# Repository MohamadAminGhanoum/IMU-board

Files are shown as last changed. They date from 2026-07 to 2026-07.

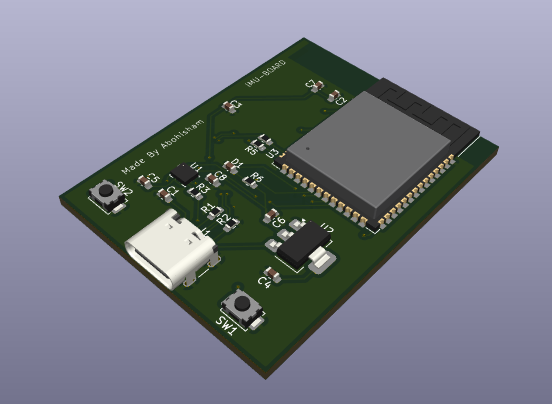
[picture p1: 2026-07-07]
IMU board assets/Screenshot 2026-07-07 at 11.47.12.png

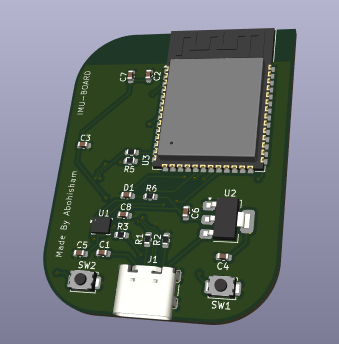
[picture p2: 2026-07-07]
IMU board assets/Screenshot 2026-07-07 at 11.54.32.png

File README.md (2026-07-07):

# IMU-board
Im making a module that has small sensors on the pcbs, which will give me motion data, which i will track and recieve on either my phone or computer using the usb-c. i have planned to use components to measure acceleration, and gestures, etc. i have done some research, and i have decided to use the ST ISM330DHCXTR which can be found from LCSC electronics.
I want for instance to test this when im inside the car, and i want to see what data it will provide me, and whether it is accurate compared to my phone (and possibly whether my phone is accurate compared with it ;).



## Schematics:



## PCB



## BOM

|Id |Name |Footprint |Quantity |Price |Value |Supplier |LINK: |
|---|---|---|---|---|---|---|---|
|1  |SW2 |SW_SPST_TS-1088-xR020 |1 |0 |enable |Self-sourced| |
|2  |SW1 |SW_SPST_TS-1088-xR020 |1 |0 |boot |Self-sourced| |
|3  |R5,R4 |R_0603_1608Metric |2 |0 |33r |Self-sourced| |
|4  |U3 |ESP32-S3-WROOM-1 |1 |5.53  |ESP32-S3-WROOM-1 |LCSC |https://www.lcsc.com/product-detail/C2913202.html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|
|5  |U2 |SOT-223-3_TabPin2 |1 |1 |AMS1117-3.3 |LCSC |https://www.lcsc.com/product-detail/C6186.html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 |
|6  |U1 |LGA-14_3x2.5mm_P0.5mm_LayoutBorder3x4y |1 |6.28  |ISM330DHCX |LCSC |https://www.lcsc.com/product-detail/C2655101.html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 |
|7  |R6 |R_0603_1608Metric |1 |0 |1k |Self-sourced| |
|8  |R3 |R_0603_1608Metric |1 |0 |10k |Self-sourced| |
|9  |R2,R1 |R_0603_1608Metric |2 |0 |5.1k |Self-sourced| |
|10 |J1 |USB_C_Receptacle_GCT_USB4105-xx-A_16P_TopMnt_Horizontal|1 |0 |USB_C_Receptacle_USB2.0_14P|self-sourced| |
|11 |D1 |C_0603_1608Metric |1 |0 |LED |self-sourced| |
|12 |C8,C7,C6,C5,C4,C3|C_0603_1608Metric |6 |0 |100nF |self-sourced| |
|13 |C2 |C_0603_1608Metric |1 |0 |22 uF |self-sourced| |
|14 |C1 |C_0603_1608Metric |1 |0 |10 uF |self-sourced| |
|15 |PCB | | |6 | |JLCPCB | |
| | | | | | | | |
| | | |Total cost with shipping:|36 USD| | | |

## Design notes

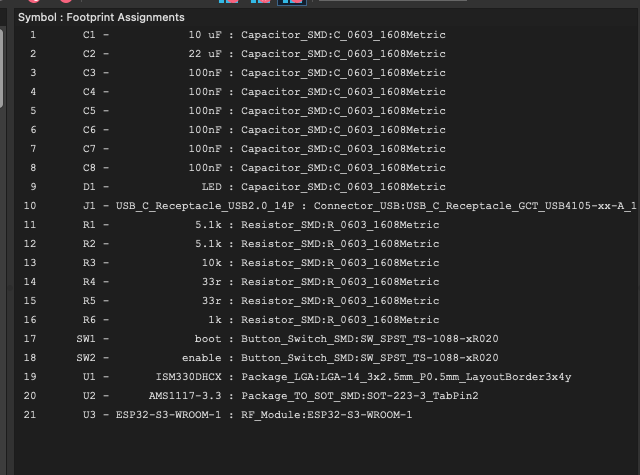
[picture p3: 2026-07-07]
IMU board assets/Screenshot 2026-07-07 at 11.48.55.png

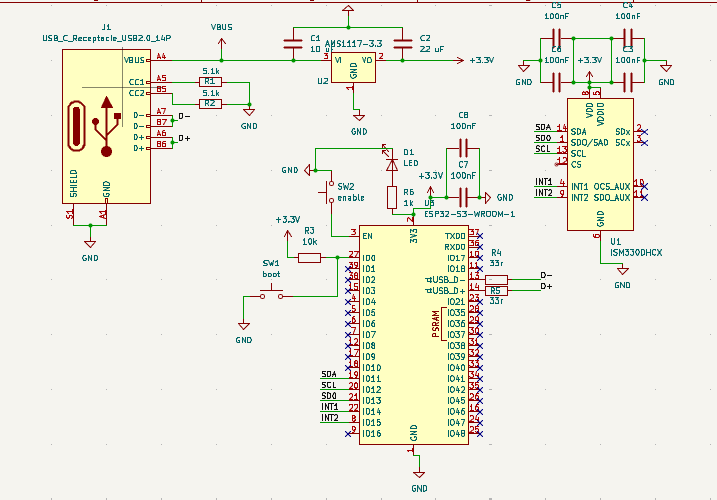
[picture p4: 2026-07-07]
IMU board assets/Screenshot 2026-07-07 at 11.03.52.png

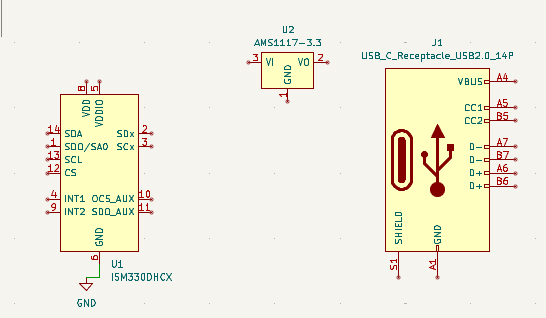
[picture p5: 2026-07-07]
IMU board assets/Screenshot 2026-07-06 at 20.02.14.png

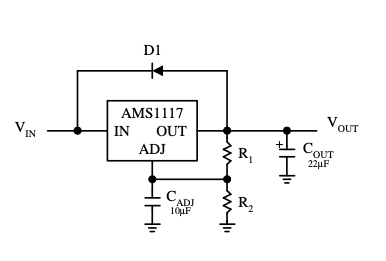
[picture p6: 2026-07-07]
IMU board assets/Screenshot 2026-07-07 at 10.36.37.png

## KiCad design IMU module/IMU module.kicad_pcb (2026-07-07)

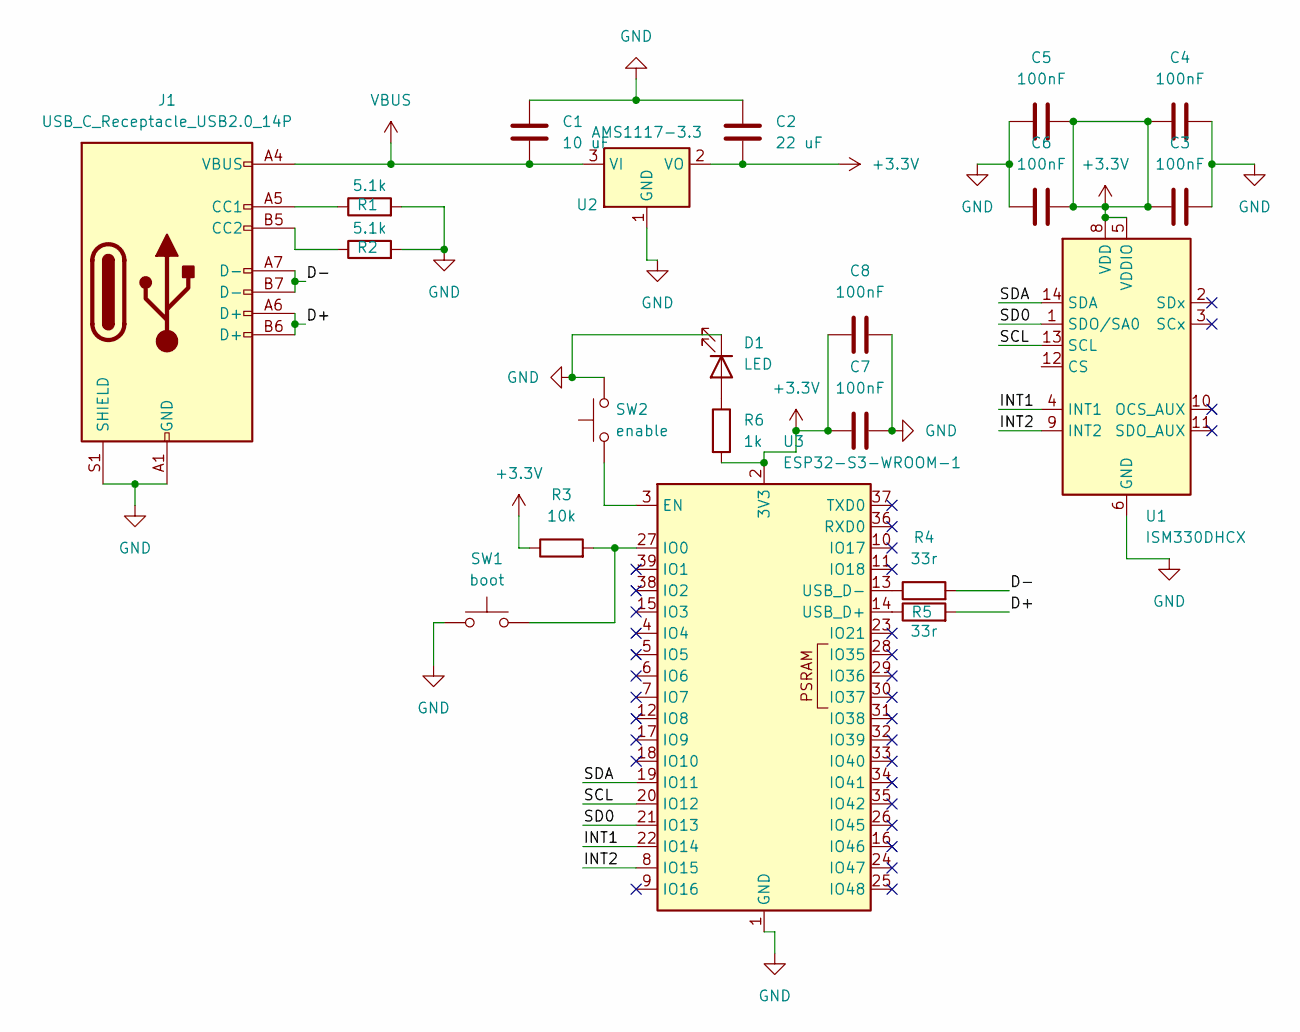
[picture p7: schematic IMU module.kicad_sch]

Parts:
C1: 10 uF; C_0603_1608Metric
C2: 22 uF; C_0603_1608Metric
C3, C4, C5, C6, C7, C8: 100nF; C_0603_1608Metric
D1: LED; C_0603_1608Metric
J1: USB_C_Receptacle_USB2.0_14P; USB_C_Receptacle_GCT_USB4105-xx-A_16P_TopMnt_Horizontal
R1, R2: 5.1k; R_0603_1608Metric
R3: 10k; R_0603_1608Metric
R4, R5: 33r; R_0603_1608Metric
R6: 1k; R_0603_1608Metric
SW1: boot; SW_SPST_TS-1088-xR020
SW2: enable; SW_SPST_TS-1088-xR020
U1: ISM330DHCX; LGA-14_3x2.5mm_P0.5mm_LayoutBorder3x4y
U2: AMS1117-3.3; SOT-223-3_TabPin2
U3: ESP32-S3-WROOM-1

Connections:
+3.3V: C2.2, C3.1, C4.1, C5.2, C6.2, C7.1, C8.1, R3.1, R6.2, U1.5 (VDDIO), U1.8 (VDD), U2.2 (VO), U3.2 (3V3)
/D+: J1.A6 (D+), J1.B6 (D+), R5.2
/D-: J1.A7 (D-), J1.B7 (D-), R4.2
/INT1: U1.4 (INT1), U3.22 (IO14)
/INT2: U1.9 (INT2), U3.8 (IO15)
/SCL: U1.13 (SCL), U3.20 (IO12)
/SD0: U1.1 (SDO/SA0), U3.21 (IO13)
/SDA: U1.14 (SDA), U3.19 (IO11)
GND: C1.1, C2.1, C3.2, C4.2, C5.1, C6.1, C7.2, C8.2, D1.1 (K), J1.A1 (GND), J1.A12 (GND), J1.B1 (GND), J1.B12 (GND), J1.S1 (SHIELD), R1.2, R2.2, SW1.1, SW2.2, U1.6 (GND), U1.7 (GND), U2.1 (GND), U3.1 (GND), U3.40 (GND), U3.41 (GND)
unnamed: D1.2 (A), R6.1
unnamed: J1.A5 (CC1), R1.1
unnamed: J1.B5 (CC2), R2.1
unnamed: SW2.1, U3.3 (EN)
unnamed: R3.2, SW1.2, U3.27 (IO0)
unnamed: R5.1, U3.14 (USB_D+)
unnamed: R4.1, U3.13 (USB_D-)
VBUS: C1.2, J1.A4 (VBUS), J1.A9 (VBUS), J1.B4 (VBUS), J1.B9 (VBUS), U2.3 (VI)

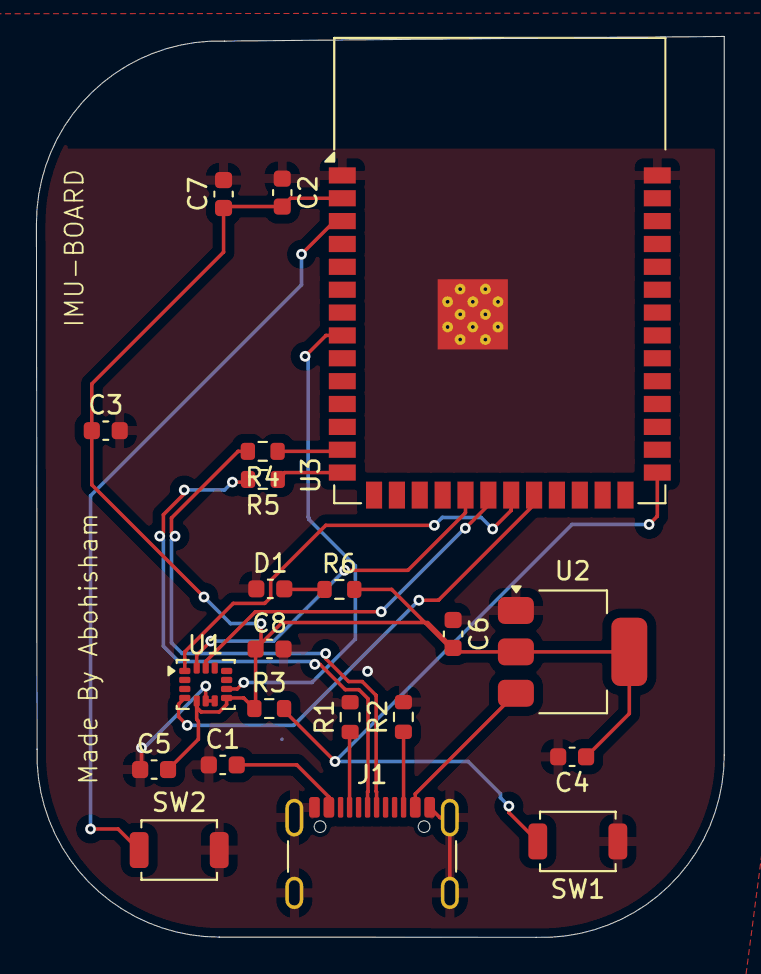
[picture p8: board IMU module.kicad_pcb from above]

Board: 2 copper layers, 38.2 x 50.0 mm, 21 parts (0 on the bottom side), 17 nets.

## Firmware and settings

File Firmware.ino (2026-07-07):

#include <Wire.h>
#include <SPI.h>
#include <Adafruit_ISM330DHCX.h>

// Define SPI pins according to our custom hardware schematic map
#define IMU_CS   10
#define IMU_SCK  12
#define IMU_MOSI 11
#define IMU_MISO 13

// Create the sensor object using hardware SPI configuration
Adafruit_ISM330DHCX ism330;

void setup(void) {
  // Initialize native USB Serial
  Serial.begin(115200);
  while (!Serial) {
    delay(10); // Wait for USB serial port to connect (needed for native USB-C)
  }

  Serial.println("--- ESP32-S3 ISM330DHCX Custom Board Test ---");

  // Initialize the IMU using hardware SPI pins passed to the library wrapper
  // We explicitly override the default pins to match our custom layout mapping
  if (!ism330.begin_SPI(IMU_CS, IMU_SCK, IMU_MISO, IMU_MOSI)) {
    Serial.println("Error: Could not find a valid ISM330DHCX chip over SPI! Check hardware connections.");
    while (1) {
      delay(10);
    }
  }

  Serial.println("ISM330DHCX successfully initialized over SPI!");

  // --- Configure Sensor Ranges & Data Rates ---
  // Accelerometer range: +/- 4G
  ism330.setAccelRange(LSM6DS_ACCEL_RANGE_4_G);
  
  // Gyroscope range: +/- 500 degrees per second
  ism330.setGyroRange(LSM6DS_GYRO_RANGE_500_DPS);

  // Set Output Data Rate (ODR) to 104 Hz for stable telemetry streaming
  ism330.setAccelDataRate(LSM6DS_RATE_104_HZ);
  ism330.setGyroDataRate(LSM6DS_RATE_104_HZ);

  Serial.println("Sensor operational configurations locked.");
}

void loop() {
  // Instantiating normalized event storage structures
  sensors_event_t accel;
  sensors_event_t gyro;
  sensors_event_t temp;

  // Fetch packed metrics over the SPI bus interface
  ism330.getEvent(&accel, &gyro, &temp);

  // --- Print Telemetry Stream over Native USB-C Data Lines ---
  Serial.print("ACCEL (m/s^2) -> X: ");
  Serial.print(accel.acceleration.x, 3);
  Serial.print(" \tY: ");
  Serial.print(accel.acceleration.y, 3);
  Serial.print(" \tZ: ");
  Serial.print(accel.acceleration.z, 3);

  Serial.print("  |  GYRO (rad/s) -> X: ");
  Serial.print(gyro.gyro.x, 4);
  Serial.print(" \tY: ");
  Serial.print(gyro.gyro.y, 4);
  Serial.print(" \tZ: ");
  Serial.println(gyro.gyro.z, 4);

  // Sample delay throttling to match the 104 Hz device refresh rate interval (~10ms)
  delay(10);
}
